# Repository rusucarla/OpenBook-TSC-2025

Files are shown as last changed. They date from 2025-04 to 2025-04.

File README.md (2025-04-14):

# Proiect TSC 2025 - OpenBook

## 1.O diagramă bloc cu toate componentele proiectului și cum sunt ele legate

```mermaid
graph TD
    
    USB["USB-C Connector(ESD Protection)"] -->|5V| CHG["Battery Charger (MCP73831)"]
    CHG -->|Charging| BATT["Li-Po Battery (2500mAh)"]
    BATT --> LDO["3.3V LDO Regulator (XC6220)"]

    LDO -->|3.3V| ESP["ESP32-C6-WROOM-1(MCU)"]

    ESP -- I2C --> RTC["Real Time Clock(DS3231)"]
    ESP -- I2C --> BME["Environmental Sensor(BME688)"]
    ESP -- I2C --> FUEL["Battery Fuel Gauge(MAX17048)"]
    ESP -- I2C --> QWIIC["Qwiic / Stemma QT"]

    ESP -- SPI --> FLASH["External NOR Flash(W25Q512)"]
    ESP -- SPI --> SD["MicroSD Card Slot"]
    ESP -- SPI --> EPD_HEADER["E-Paper Display Header"]

    EPD_HEADER --> EPD_DRIVER["EPD Driver Circuit"]
    EPD_DRIVER --> EPD_POW["EPD HV Power"]
    LDO --> EPD_HEADER

    ESP -- GPIO --> BUTTONS["3x Buttons:BOOT, CHANGE, RESET"]

    USB -- USB D+/D- --> ESP
```
## 2. BOM-ul (coloanele cu N/A sunt duplicate ale unui tip de componentă și am pus date doar la prima apariție a acelui tip de componentă)

Încă o observație, TP-ul si SJ-urile au fost modelate de către mine și astfel nu au model cu link sau data sheet.

| Name of component | Device | Check Prices | DataSheet |
|---|---|---|---|
| BOOT_BUTTON | BUTTON_CUSYOMV1 | https://industry.panasonic.com/global/en/products/control/switch/light-touch/number/evqpuj02k | https://industry.panasonic.com/global/en/products/control/switch/light-touch/number/evqpuj02k |
| C1 | ESP32_WROVER_EAGLE-LTSPICE_CC0402 | https://industry.panasonic.com/global/en/products/control/switch/light-touch/number/evqpuj02k | https://industry.panasonic.com/global/en/products/control/switch/light-touch/number/evqpuj02k |
| C1_BAT | ESP32_WROVER_EAGLE-LTSPICE_CC0402 | #N/A | #N/A |
| C1_BAT1 | EAGLE-LTSPICE_CC0402 | #N/A | #N/A |
| C1_BAT2 | EAGLE-LTSPICE_CC0402 | #N/A | #N/A |
| C2 | ESP32_WROVER_EAGLE-LTSPICE_CC0402 | #N/A | #N/A |
| C2_BAT\ | ESP32_WROVER_EAGLE-LTSPICE_CC0402 | #N/A | #N/A |
| C3 | RCL_CPOL-EUCT3528 | #N/A | #N/A |
| C4 | ESP32_WROVER_EAGLE-LTSPICE_CC0402 | #N/A | #N/A |
| C4_USB | ESP32_WROVER_EAGLE-LTSPICE_CC0402 | #N/A | #N/A |
| C5 | ESP32_WROVER_EAGLE-LTSPICE_CC0402 | #N/A | #N/A |
| C5_USB | ESP32_WROVER_EAGLE-LTSPICE_CC0402 | #N/A | #N/A |
| C6 | ESP32_WROVER_EAGLE-LTSPICE_CC0402 | #N/A | #N/A |
| C7 | ESP32_WROVER_EAGLE-LTSPICE_CC0402 | #N/A | #N/A |
| C8 | ESP32_WROVER_EAGLE-LTSPICE_CC0402 | #N/A | #N/A |
| C9 | EAGLE-LTSPICE_CC0402 | #N/A | #N/A |
| C10 | ESP32_WROVER_EAGLE-LTSPICE_CC0402 | #N/A | #N/A |
| C10_SUPERCAP | CPH3225A | https://www.snapeda.com/parts/CPH3225A/Seiko+Instruments/view-part/?ref=eda | https://www.snapeda.com/parts/CPH3225A/Seiko+Instruments/view-part/?ref=eda |
| CHANGE_BUTTON | BUTTON_CUSYOMV1 | https://industry.panasonic.com/global/en/products/control/switch-light-touch/number/evqpuj02k | https://industry.panasonic.com/global/en/products/control/switch-light-touch/number/evqpuj02k |
| CHG_LED | ADAFRUIT_LEDCHIP-LED0603 | https://www.snapeda.com/parts/KP-1608SURCK/Kingbright/view-part/?ref=search&t=LED%200603 | https://www.snapeda.com/parts/KP-1608SURCK/Kingbright/view-part/?ref=search&t=LED%200603 |
| C_DELAY | ESP32_WROVER_EAGLE-LTSPICE_CC0402 | #N/A | #N/A |
| D1 | USBLC6-2SC6Y | https://www.snapeda.com/parts/USBLC6-2SC6Y/STMicroelectronics/view-part/?ref=eda | https://www.snapeda.com/parts/USBLC6-2SC6Y/STMicroelectronics/view-part/?ref=eda |
| D2 | ESP32_WROVER_AVX---SD0805S020S1R0_AVX_... | https://eu.mouser.com/ProductDetail/KYOCERA-AVX/SD0805S020S1R0?qs=jCA%252BPfw4LHbpkAoSnwrdjw%3D%3D | http://datasheets.avx.com/schottky.pdf |
| D3 | MBR0530 | https://eu.mouser.com/ProductDetail/KYOCERA-AVX/SD0805S020S1R0?qs=jCA%252BPfw4LHbpkAoSnwrdjw%3D%3D | https://eu.mouser.com/ProductDetail/KYOCERA-AVX/SD0805S020S1R0?qs=jCA%252BPfw4LHbpkAoSnwrdjw%3D%3D |
| D4 | MBR0530 | https://www.snapeda.com/parts/MBR0530/Onsemi/view-part/?ref=eda | https://www.snapeda.com/parts/MBR0530/Onsemi/view-part/?ref=eda |
| D5 | MBR0530 | https://www.snapeda.com/parts/MBR0530/Onsemi/view-part/?ref=eda | https://www.snapeda.com/parts/MBR0530/Onsemi/view-part/?ref=eda |
| D6 | PGB1010603MR | https://www.snapeda.com/parts/PGB1010603MR/Littelfuse/view-part/?ref=eda | https://www.snapeda.com/parts/PGB1010603MR/Littelfuse/view-part/?ref=eda |
| D7 | ESP32_WROVER_AVX---SD0805S020S1R0_AVX_... | https://eu.mouser.com/ProductDetail/KYOCERA-AVX/SD0805S020S1R0?qs=jCA%252BPfw4LHbpkAoSnwrdjw%3D%3D | http://datasheets.avx.com/schottky.pdf |
| D8 | PGB1010603MR | https://www.snapeda.com/parts/PGB1010603MR/Littelfuse/view-part/?ref=eda | https://www.snapeda.com/parts/PGB1010603MR/Littelfuse/view-part/?ref=eda |
| D9 | PGB1010603MR | https://www.snapeda.com/parts/PGB1010603MR/Littelfuse/view-part/?ref=eda | https://www.snapeda.com/parts/PGB1010603MR/Littelfuse/view-part/?ref=eda |
| D10 | PGB1010603MR | https://www.snapeda.com/parts/PGB1010603MR/Littelfuse/view-part/?ref=eda | https://www.snapeda.com/parts/PGB1010603MR/Littelfuse/view-part/?ref=eda |
| D11 | PGB1010603MR | https://www.snapeda.com/parts/PGB1010603MR/Littelfuse/view-part/?ref=eda | https://www.snapeda.com/parts/PGB1010603MR/Littelfuse/view-part/?ref=eda |
| D12 | PGB1010603MR | https://www.snapeda.com/parts/PGB1010603MR/Littelfuse/view-part/?ref=eda | https://www.snapeda.com/parts/PGB1010603MR/Littelfuse/view-part/?ref=eda |
| EPD_C1 | ESP32_WROVER_EAGLE-LTSPICE_CC0402 | #N/A | #N/A |
| EPD_C2 | ESP32_WROVER_EAGLE-LTSPICE_CC0402 | #N/A | #N/A |
| EPD_C5 | ESP32_WROVER_EAGLE-LTSPICE_CC0402 | #N/A | #N/A |
| EPD_C6 | ESP32_WROVER_EAGLE-LTSPICE_CC0402 | #N/A | #N/A |
| EPD_C7 | ESP32_WROVER_EAGLE-LTSPICE_CC0402 | #N/A | #N/A |
| EPD_C8 | ESP32_WROVER_EAGLE-LTSPICE_CC0402 | #N/A | #N/A |
| EPD_C9 | ESP32_WROVER_EAGLE-LTSPICE_CC0402 | #N/A | #N/A |
| EPD_C10 | ESP32_WROVER_EAGLE-LTSPICE_CC0402 | #N/A | #N/A |
| EPD_C11 | ESP32_WROVER_EAGLE-LTSPICE_CC0402 | #N/A | #N/A |
| EPD_C12 | ESP32_WROVER_EAGLE-LTSPICE_CC0402 | #N/A | #N/A |
| IC1 | BD5229G-TR | https://componentsearchengine.com/part-view/BD5229G-TR/ROHM%20Semiconductor | https://componentsearchengine.com/part-view/BD5229G-TR/ROHM%20Semiconductor |
| IC4 | XC6220A331MR-G | https://componentsearchengine.com/part-view/XC6220A331MR-G/Torex | https://componentsearchengine.com/part-view/XC6220A331MR-G/Torex |
| J1 | FH34SRJ-24S-0.5SH_99_ | https://componentsearchengine.com/part-view/XC6220A331MR-G/Torex | https://componentsearchengine.com/part-view/XC6220A331MR-G/Torex |
| J2 | SAMACSYS_PARTS_USB4110-GF-A | https://componentsearchengine.com/part-view/USB4110-GF-A/GCT%20(GLOBAL%20CONNECTOR%20TECHNOLOGY | https://componentsearchengine.com/part-view/USB4110-GF-A/GCT%20(GLOBAL%20CONNECTOR%20TECHNOLOGY |
| J3 | QWIIC_CONNECTORJS-1MM | #N/A | #N/A |
| J4 | 112A-TAAR-R03_ATTEND | https://store.comet.srl.ro/Catalogue/Product/43497/ | https://store.comet.srl.ro/Catalogue/Product/43497/ |
| L1 | 744043680IND_4828-WE-TPC_WRE | https://eu.mouser.com/ProductDetail/Wurth-Elektronik/744043680?qs=PGXP4M47uW6VkZq%252BkzjrHA%3D%3D | https://eu.mouser.com/ProductDetail/Wurth-Elektronik/744043680?qs=PGXP4M47uW6VkZq%252BkzjrHA%3D%3D |
| PFMF.050.1 | ESP32C6_VARISTORCN1812 | https://www.mouser.co.uk/ProductDetail/EPCOS-TDK/B72520T0350K062?qs=dEfas%2FXlABIszF52uu7vrg%3D%3D | https://www.mouser.co.uk/ProductDetail/EPCOS-TDK/B72520T0350K062?qs=dEfas%2FXlABIszF52uu7vrg%3D%3D |
| Q1 | ESP32_WROVER_SPARKFUN-DISCRETESEMI_MOSFET_...| https://componentsearchengine.com/part-view/DMG2305UX-7/Diodes%20Incorporated | https://componentsearchengine.com/part-view/DMG2305UX-7/Diodes%20Incorporated |
| Q2 | ESP32_WROVER_SPARKFUN-DISCRETESEMI_MOSFET_...| #N/A | #N/A |
| Q3 | D8 | https://componentsearchengine.com/part-view/SI1308EDL-T1-GE3/Vishay | https://componentsearchengine.com/part-view/SI1308EDL-T1-GE3/Vishay |
| R1 | ESP32_WROVER_EAGLE-LTSPICE_RR0402 | #N/A | #N/A |
| R1-PINH | ESP32_WROVER_EAGLE-LTSPICE_RR0402 | #N/A | #N/A |
| R1-PINH1 | ESP32_WROVER_EAGLE-LTSPICE_RR0402 | #N/A | #N/A |
| R1_BAT | ESP32_WROVER_EAGLE-LTSPICE_RR0402 | #N/A | #N/A |
| R1_PWRUSB | ESP32_WROVER_EAGLE-LTSPICE_RR0402 | #N/A | #N/A |
| R2 | ESP32_WROVER_EAGLE-LTSPICE_RR0402 | https://componentsearchengine.com/part-view/R0402%201%25%20100%20K%20(RC0402FR-07100KL | https://componentsearchengine.com/part-view/R0402%201%25%20100%20K%20(RC0402FR-07100KL |
| R2-PINH | ESP32_WROVER_EAGLE-LTSPICE_RR0402 | #N/A | #N/A |
| R2-PINH1 | ESP32_WROVER_EAGLE-LTSPICE_RR0402 | #N/A | #N/A |
| R2-USB | ESP32_WROVER_EAGLE-LTSPICE_RR0402 | #N/A | #N/A |
| R2-USB1 | ESP32_WROVER_EAGLE-LTSPICE_RR0402 | #N/A | #N/A |
| R2_BAT | ESP32_WROVER_EAGLE-LTSPICE_RR0402 | #N/A | #N/A |
| R3 | ESP32_WROVER_EAGLE-LTSPICE_RR0402 | #N/A | #N/A |
| R4 | ESP32_WROVER_EAGLE-LTSPICE_RR0402 | #N/A | #N/A |
| R5 | ESP32_WROVER_EAGLE-LTSPICE_RR0402 | #N/A | #N/A |
| R6 | ESP32_WROVER_EAGLE-LTSPICE_RR0402 | #N/A | #N/A |
| R7 | ESP32_WROVER_EAGLE-LTSPICE_RR0402 | #N/A | #N/A |
| R8 | ESP32_WROVER_EAGLE-LTSPICE_RR0402 | #N/A | #N/A |
| R9 | ESP32_WROVER_EAGLE-LTSPICE_RR0402 | #N/A | #N/A |
| R10 | ESP32_WROVER_EAGLE-LTSPICE_RR0402 | #N/A | #N/A |
| RESET_BUTTON | BUTTON_CUSYOMV1 | https://industry.panasonic.com/global/en/products/control/switch/light-touch/number/evqpuj02k | https://industry.panasonic.com/global/en/products/control/switch/light-touch/number/evqpuj02k |
| R_BOOT | ESP32_WROVER_EAGLE-LTSPICE_RR0402 | #N/A | #N/A |
| R_CAPACITOR | ESP32_WROVER_EAGLE-LTSPICE_RR0402 | #N/A | #N/A |
| R_CHANGE | ESP32_WROVER_EAGLE-LTSPICE_RR0402 | #N/A | #N/A |
| R_CL1 | ESP32_WROVER_EAGLE-LTSPICE_RR0402 | #N/A | #N/A |
| R_RESET | ESP32_WROVER_EAGLE-LTSPICE_RR0402 | #N/A | #N/A |
| SENSOR2 | ESP32_WROVER_BME680_BME680 | https://www.snapeda.com/parts/BME680/Bosch/view-part/?welcome=home | https://www.snapeda.com/parts/BME680/Bosch/view-part/?welcome=home |
| SJ1 | SJ | https://grabcad.com/library/solder-jumpers-1 | https://grabcad.com/library/solder-jumpers-1 |
| TP1 | TPTP20R | #N/A | #N/A |
| TP2 | TPTP20R | #N/A | #N/A |
| TP3 | TPTP20R | #N/A | #N/A |
| TP4 | TPTP20R | #N/A | #N/A |
| TP5 | TPTP20R | #N/A | #N/A |
| TP6 | TPTP20R | #N/A | #N/A |
| TP7 | TPTP20R | #N/A | #N/A |
| TP8 | TPTP20R | #N/A | #N/A |
| TP9 | TPTP20R | #N/A | #N/A |
| TP10 | TPTP20R | #N/A | #N/A |
| TP11 | TPTP20R | #N/A | #N/A |
| TP12 | TPTP20R | #N/A | #N/A |
| TP13 | TPTP20R | #N/A | #N/A |
| TP14 | TPTP20R | #N/A | #N/A |
| TP15 | TPTP20R | #N/A | #N/A |
| TP16 | TPTP20R | #N/A | #N/A |
| TP17 | TPTP20R | #N/A | #N/A |
| U1 | W25Q512JVEIQ | https://www.snapeda.com/parts/W25Q512JVEIQ/Winbond+Electronics/view-part/?ref=eda | https://www.snapeda.com/parts/W25Q512JVEIQ/Winbond+Electronics/view-part/?ref=eda |
| U2 | ESP32-C6-WROOM-1-N8 | https://www.snapeda.com/parts/ESP32-C6-WROOM-1-N8/Espressif+Systems/view-part/?ref=eda | https://www.snapeda.com/parts/ESP32-C6-WROOM-1-N8/Espressif+Systems/view-part/?ref=eda |
| U3 | DS3231SN# | https://www.snapeda.com/parts/DS3231SN%23/Analog+Devices/view-part/?ref=eda | https://www.snapeda.com/parts/DS3231SN%23/Analog+Devices/view-part/?ref=eda |
| U4 | MAX17048G+T10 | https://www.snapeda.com/parts/MAX17048G+T10/Analog+Devices/view-part/?ref=eda | https://www.snapeda.com/parts/MAX17048G+T10/Analog+Devices/view-part/?ref=eda |
| U5 | ESP32_WROVER_SPARKFUN-IC-POWER_MCP73831 | https://eu.mouser.com/ProductDetail/Microchip-Technology/MCP73831T-2ACI-OT?qs=yUQqVecv4qvbBQBGbHx0Mw%3D%3Dcf | https://eu.mouser.com/ProductDetail/Microchip-Technology/MCP73831T-2ACI-OT?qs=yUQqVecv4qvbBQBGbHx0Mw%3D%3Dcf |

## 3. Descrierea in detaliu a functionalitatilor hardware 

### 1. Microcontroller – ESP32-C6

- **Procesor**: 32-bit RISC-V, cu frecvență de până la 160MHz.
    
- **Memorie**: 512KB SRAM intern și 8MB flash extern (W25Q512JVEIQ).
    
- **Conectivitate**: Wi-Fi 6 (802.11ax), Bluetooth 5 (LE), USB 2.0 (full-speed).
    
- **Periferice**: SPI, I²C, UART, GPIO multiple.
    
- **Consum**: Posibilitate de moduri low-power (sleep, deep sleep).
---

### 2. Afișajul E-Paper (7.5 inch)

- **Model**: Waveshare (sau echivalent) cu rezoluție 800×480.
    
- **Interfață**: 4-wire SPI + semnale de control (CS, DC, RST, BUSY).
    
- **Consum**: Foarte redus în mod static (după refresh), dar necesită un curent mai mare în timpul refresh-ului (aprox. 15–25mA, în funcție de modul de actualizare).

**De ce l-am ales?**  
E-paper consumă energie doar când reîmprospătează imaginea. Este ideal pentru un e-reader, deoarece menține afișajul vizibil fără consum suplimentar.

---

### 3. Senzor de Mediu – BME688

- **Parametri măsurați**: Temperatură, Umiditate, Presiune și Calitate aer (VOC/eCO2).
    
- **Interfață**: I²C la 400kHz (SDA și SCL).
    
- **Consum**: Foarte mic (în jur de 2.1µA în standby și până la câteva mA în mod de măsurare).

**De ce BME688?**  
Integrează într-un singur cip mai multe tipuri de măsurători de mediu, util pentru a afișa date despre condițiile de citire (temperatură, umiditate etc.).

---

### 4. Baterie și Managementul Energiei

- **Baterie Li-Po 2500mAh** (3.7V nominal).
    
- **IC de Încărcare**: MCP73831 (Microchip) – încărcare Li-Po prin USB-C (până la 1A).
    
- **Fuel Gauge**: MAX17048 – monitorizează nivelul de încărcare, tensiunea și starea bateriei (I²C).
    
- **LDO**: XC6220A331MR-G (exemplu) sau echivalent, pentru a asigura 3.3V stabil pentru microcontroller și restul componentelor.

**De ce aceste componente?**

- MCP73831 este un controler simplu, fiabil și compatibil cu USB.
    
- MAX17048 oferă date precise despre nivelul bateriei și poate alerta asupra unei baterii descărcate.

---

### 5. Butoane (3x Tactile Switch)

- **Tip**: Tactile switch Panasonic (sau echivalent).
    
- **Funcții**: Navigare meniu, selectare opțiune, întoarcere pagină etc.
    
- **Conexiune**: Fiecare buton se leagă la un GPIO al ESP32-C6 printr-un circuit de debouncing (rezistență și condensator) sau se poate face debouncing în firmware.

---

### 6. USB-C Port

- **Rol**: Încărcare baterie + Transfer de date (USB 2.0 full-speed).
    
- **Protecții**: ESD (USBLC6-2SC6Y) + rezistențe de terminare.
    
- **Posibilitate**: Actualizări firmware prin USB (bootloader + tool extern) sau direct OTA prin Wi-Fi.

---

### 7. Conector Qwiic (I²C)

- Conector standard cu 4 pini: VCC, GND, SDA, SCL.
    
- Permite atașarea rapidă a altor senzori sau module I²C (expansiune, testare, prototipare rapidă).

---

### 8. SD Memory Card Connector (112A-TAAR-R03)

- **Rol**: Posibilitate de stocare externă pentru e-book-uri, log-uri sau update-uri firmware.
    
- **Interfață**: Poate fi SD (1-bit / 4-bit) sau SPI, în funcție de configurația firmware-ului.

---

### 9. RTC – DS3231

- **Funcție**: Asigură un ceas de timp real foarte precis.
    
- **Interfață**: I²C (aceeași magistrală cu BME688 și MAX17048).
    
- **Backup**: Supercondensator sau baterie secundară pentru a menține timpul și în absența alimentării principale.

---

### 10. Memorii Suplimentare

- **W25Q512JVEIQ** (Flash extern) – conectat la ESP32-C6 prin SPI dedicat (quad SPI).
    
    - Aici se stochează firmware-ul și datele mari (e-book-uri etc.).

---

### Comunicarea și Interfețele

1. **SPI**:
    
    - Ecranul e-paper (4-wire SPI).
        
    - Flash extern (quad SPI dedicat, pinii sunt în mare parte fixați de designul ESP32-C6).
        
2. **I²C**:
    
    - Senzorul BME688.
        
    - Fuel Gauge MAX17048.
        
    - RTC DS3231.
        
    - Qwiic Connector (pentru potențiale extensii).
        
3. **USB 2.0**:
    
    - Date + alimentare/încărcare prin USB-C.
        
4. **GPIO**:
    
    - Butoane (3x intrări digitale).
        
    - Eventual semnale de control suplimentare (reset display, busy pin display, semnal de enable alimentare etc.).

### Calcul Simplificat al Consumului

| Modul | Consum tipic |
| --- | --- |
| **ESP32-C6** (activ) | ~80mA (Wi-Fi activ) / < 10mA (idle) |
| **E-Paper** (refresh) | ~15–25mA (doar în timpul refresh-ului) |
| **BME688** (activ) | ~3.6mA (peak) / 2.1µA (sleep) |
| **MAX17048** (fuel gauge) | ~50µA |
| **DS3231** (RTC) | ~3.5mA (activ) / <1µA (back-up) |
| **MCP73831** (charger) | Consum diferit în funcție de curentul de încărcare:<br>- *500 mA* (standard)<br>- *1 A* (dacă design-ul suportă încărcare mai rapidă) |

#### Mod Activ + Wi-Fi

- În timpul activării Wi-Fi (pentru descărcarea e-book-urilor sau actualizarea conținutului) și al refresh-ului ecranului e-paper, **consumul total** al sistemului (ESP32-C6 + e-paper + senzori) poate ajunge la **100–150 mA**.  
- Această valoare **include** ESP32-C6 în mod Wi-Fi activ, senzori și curentul suplimentar de ~15–25 mA în timpul refresh-ului e-paper.

#### Deep Sleep / Standby

- **ESP32-C6** poate intra în deep sleep cu un consum de ordinul zecilor de microamperi (~70 µA dacă este bine optimizat și cu periferice oprite).  
- Ceilalți senzori și componente pot fi dezactivați sau puși în moduri de consum redus, contribuind cu încă câțiva µA (RTC, fuel gauge etc.).  
- Totalul în deep sleep poate fi menținut sub **100 µA** dacă sunt implementate corect modurile de consum redus pentru fiecare componentă.

#### Exemplu de Calcul pentru Autonomie

Cu o **baterie de 2500 mAh**, considerăm un ciclu de funcționare ipotetic:

- **95% din timp** dispozitivul este în deep sleep (~70 µA).  
- **5% din timp** este în mod activ (~120 mA), cu Wi-Fi pornit și e-paper folosit.  

1. **Consum în deep sleep (95% din timp)**  
     $I_{\mathrm{deep\_sleep}} = 70\,\mu A$
   
3. **Consum în mod activ (5% din timp)**  
   $I_{\mathrm{activ}} \approx 120\,mA$

4. **Media consumului orar**  
   $I_{\mathrm{mediu}} = 0.95 \times 70\,\mu A + 0.05 \times 120\,mA = (0.95 \times 0.07\,mA) + (0.05 \times 120\,mA) = 0.0665\,mA + 6\,mA = \approx 6.07\,mA$

5. **Autonomie teoretică**  
   $\text{Autonomie} = \frac{Capacitatea\ Bateriei}{I_{\mathrm{mediu}}}
     \approx \frac{2500\,mAh}{6.07\,mA} \approx 412\,ore \approx 17\,zile$

Dacă mai optimizăm timpul activ (de exemplu, îl reducem la 2–3% din timp) sau scădem consumul de vârf, se poate ajunge la **3–4 săptămâni**. Totuși, în practică, autonomia depinde foarte mult de:

- **Frecvența refresh-ului** e-paper  
- **Durata și frecvența conexiunilor Wi-Fi**  
- **Alți consumatori** (de ex. LED-uri de stare sau module suplimentare)

## 4. Descrieți în detaliu ce pini ai ESP32-C6 sunt folosiți pentru fiecare componentă și de ce

| Pin ESP32-C6 | Componentă / Semnal | De ce? |
| --- | --- | --- |
| **GPIO1 (SDA)** | I²C SDA (BME688, MAX17048, DS3231, Qwiic) | Partajare magistrală I²C pentru toți senzorii și RTC. |
| **GPIO2 (SCL)** | I²C SCL (BME688, MAX17048, DS3231, Qwiic) | Linia de clock pentru I²C. |
| **GPIO5** | SPI MISO (E-Paper) | Citirea datelor/statusului display-ului (dacă e suportat). |
| **GPIO6** | SPI MOSI (E-Paper) | Trimiterea datelor către e-paper. |
| **GPIO7** | SPI CLK (E-Paper) | Semnal de clock pentru e-paper. |
| **GPIO8** | SPI CS (E-Paper) | Chip Select pentru e-paper. |
| **GPIO9** | E-Paper DC (Data/Command) | Semnal care diferențiază datele de comenzile pentru afișaj. |
| **GPIO10** | E-Paper RST | Reset hardware pentru e-paper. |
| **GPIO11** | E-Paper BUSY | Intrare din display, indică dacă este ocupat. |
| **GPIO12** | Button #1 | Intrare digitală pentru buton (ex. NEXT page). |
| **GPIO13** | Button #2 | Intrare digitală pentru buton (ex. PREV page). |
| **GPIO14** | Button #3 | Intrare digitală pentru buton (ex. MENU/OK). |
| **GPIO15** | MAX17048 ALERT (opțional) | Avertizare nivel baterie scăzut. |
| **GPIO16** | USB D+ (intern la USB PHY) | Pin dedicat pentru USB 2.0. (În mod normal pin hardware fix). |
| **GPIO17** | USB D- (intern la USB PHY) | Pin dedicat pentru USB 2.0. (La fel, pin fix). |
| **GPIO18** | LED de status (opțional) | Indicator pentru diverse stări (Wi-Fi, încărcare, etc.). |
| **GPIO19** | SD Card CS (opțional) | Chip Select pentru cardul SD (dacă se folosește SPI). |
| **GPIO20** | SD Card MISO (opțional) | Intrare date de la card SD. |
| **GPIO21** | SD Card MOSI (opțional) | Ieșire date către card SD. |
| **GPIO4** | SD Card CLK (opțional) | Semnal de clock pentru card SD (SPI). |

## Orice altceva 

Design log-ul poate fi gasit pe [autodesk](https://a360.co/4kX1RTV)

Exista o incompatibilitate intre .fbrd si .brd cand vine vorba de via stching. Am pus si fisierul .fbrd pentru a se oberva diferenta.

Am decis sa redenumesc TP-urile pentru a fi mai usor de gestionat.

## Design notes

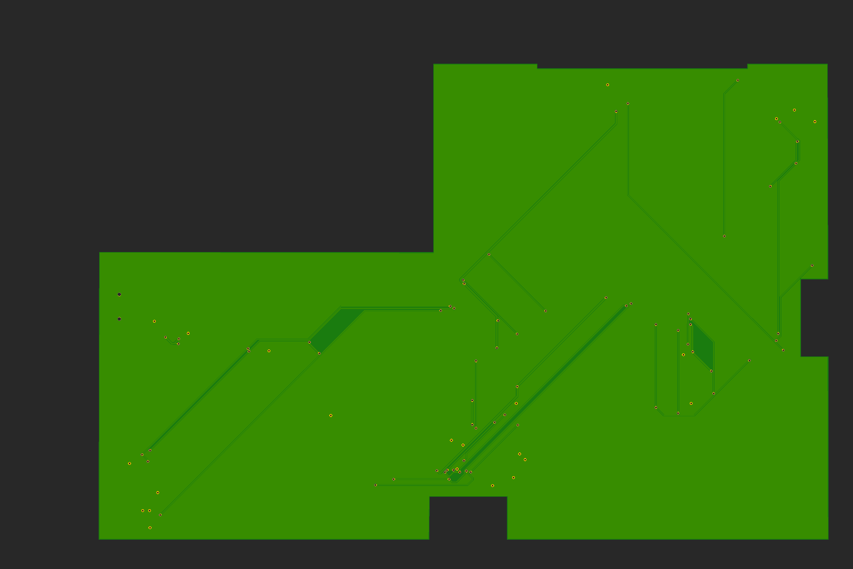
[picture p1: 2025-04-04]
Images/OpenBook_Board_View_Bottom.png

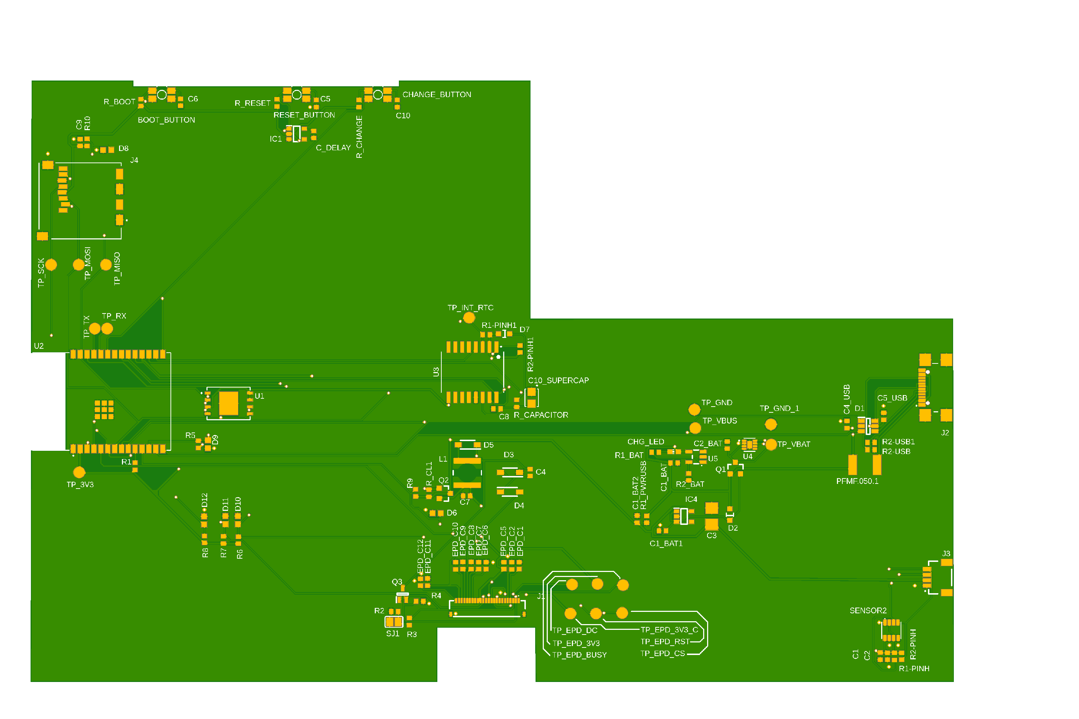
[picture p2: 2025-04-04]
Images/OpenBook_Board_View_Top.png

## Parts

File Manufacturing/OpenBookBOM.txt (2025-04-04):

Partlist exported from Fusion Hub: Fusion-Carla   Project: Admin Project  Board: OpenBook v71 at 04.04.2025 15:21

Part          Value                                                                          Device                                                                         Package                                                Description                                                                                                                                                                                                                                                                                                                                                                                                                                                                                          PARTNAME   
BOOT_BUTTON   BUTTON_CUSYOMV1                                                                BUTTON_CUSYOMV1                                                                MYBUTTON                                                                                                                                                                                                                                                                                                                                                                                                                                                                                                                                                               
C1            100nF                                                                          ESP32_WROVER_EAGLE-LTSPICE_CC0402                                              ESP32_WROVER_EAGLE-LTSPICE_C0402                       CAPACITOR, European symbol                                                                                                                                                                                                                                                                                                                                                                                                                                                                                      
C1_BAT        4.7uF                                                                          ESP32_WROVER_EAGLE-LTSPICE_CC0402                                              ESP32_WROVER_EAGLE-LTSPICE_C0402                       CAPACITOR, European symbol                                                                                                                                                                                                                                                                                                                                                                                                                                                                                      
C1_BAT1       4.7uF                                                                          ESP32_WROVER_EAGLE-LTSPICE_CC0402                                              ESP32_WROVER_EAGLE-LTSPICE_C0402                       CAPACITOR, European symbol                                                                                                                                                                                                                                                                                                                                                                                                                                                                                      
C1_BAT2       4.7uF                                                                          ESP32_WROVER_EAGLE-LTSPICE_CC0402                                              ESP32_WROVER_EAGLE-LTSPICE_C0402                       CAPACITOR, European symbol                                                                                                                                                                                                                                                                                                                                                                                                                                                                                      
C2            100nF                                                                          ESP32_WROVER_EAGLE-LTSPICE_CC0402                                              ESP32_WROVER_EAGLE-LTSPICE_C0402                       CAPACITOR, European symbol                                                                                                                                                                                                                                                                                                                                                                                                                                                                                      
C2_BAT\       4.7uF                                                                          ESP32_WROVER_EAGLE-LTSPICE_CC0402                                              ESP32_WROVER_EAGLE-LTSPICE_C0402                       CAPACITOR, European symbol                                                                                                                                                                                                                                                                                                                                                                                                                                                                                      
C3            100uF TANT                                                                     RCL_CPOL-EUCT3528                                                              RCL_CT3528                                             POLARIZED CAPACITOR, European symbol                                                                                                                                                                                                                                                                                                                                                                                                                                                                            
C4            4.7uF/25V                                                                      ESP32_WROVER_EAGLE-LTSPICE_CC0402                                              ESP32_WROVER_EAGLE-LTSPICE_C0402                       CAPACITOR, European symbol                                                                                                                                                                                                                                                                                                                                                                                                                                                                                      
C4_USB        100nF                                                                          ESP32_WROVER_EAGLE-LTSPICE_CC0402                                              ESP32_WROVER_EAGLE-LTSPICE_C0402                       CAPACITOR, European symbol                                                                                                                                                                                                                                                                                                                                                                                                                                                                                      
C5            1uF                                                                            ESP32_WROVER_EAGLE-LTSPICE_CC0402                                              ESP32_WROVER_EAGLE-LTSPICE_C0402                       CAPACITOR, European symbol                                                                                                                                                                                                                                                                                                                                                                                                                                                                                      
C5_USB        4.7µF                                                                          ESP32_WROVER_EAGLE-LTSPICE_CC0402                                              ESP32_WROVER_EAGLE-LTSPICE_C0402                       CAPACITOR, European symbol                                                                                                                                                                                                                                                                                                                                                                                                                                                                                      
C6            100nF                                                                          ESP32_WROVER_EAGLE-LTSPICE_CC0402                                              ESP32_WROVER_EAGLE-LTSPICE_C0402                       CAPACITOR, European symbol                                                                                                                                                                                                                                                                                                                                                                                                                                                                                      
C7            10uF                                                                           ESP32_WROVER_EAGLE-LTSPICE_CC0402                                              ESP32_WROVER_EAGLE-LTSPICE_C0402                       CAPACITOR, European symbol                                                                                                                                                                                                                                                                                                                                                                                                                                                                                      
C8            100nF                                                                          ESP32_WROVER_EAGLE-LTSPICE_CC0402                                              ESP32_WROVER_EAGLE-LTSPICE_C0402                       CAPACITOR, European symbol                                                                                                                                                                                                                                                                                                                                                                                                                                                                                      
C9            100nF                                                                          EAGLE-LTSPICE_CC0402                                                           ESP32_WROVER_EAGLE-LTSPICE_C0402                       CAPACITOR, European symbol                                                                                                                                                                                                                                                                                                                                                                                                                                                                                      
C10           100nF                                                                          ESP32_WROVER_EAGLE-LTSPICE_CC0402                                              ESP32_WROVER_EAGLE-LTSPICE_C0402                       CAPACITOR, European symbol                                                                                                                                                                                                                                                                                                                                                                                                                                                                                      
C10_SUPERCAP  CPH3225A""                                                                     CPH3225A""                                                                     CAPCP3225X100N                                         Cap 0.011F 3.3V 1210 Flat Check availability                                                                                                                                                                                                                                                                                                                                                                                                                                                                    
CHANGE_BUTTON BUTTON_CUSYOMV1                                                                BUTTON_CUSYOMV1                                                                MYBUTTON                                                                                                                                                                                                                                                                                                                                                                                                                                                                                                                                                               
CHG_LED                                                                                      ADAFRUIT_LEDCHIP-LED0603                                                       ADAFRUIT_CHIP-LED0603                                  LED                                                                                                                                                                                                                                                                                                                                                                                                                                                                                                             
C_DELAY       100nF                                                                          ESP32_WROVER_EAGLE-LTSPICE_CC0402                                              ESP32_WROVER_EAGLE-LTSPICE_C0402                       CAPACITOR, European symbol                                                                                                                                                                                                                                                                                                                                                                                                                                                                                      
D1            USBLC6-2SC6Y                                                                   USBLC6-2SC6Y                                                                   SOT95P280X145-6N                                       Low Cap. ESD Protection Auto SOT-23-6 STMicroelectronics USBLC6-2SC6Y, Dual Uni-Directional TVS Diode Array, 6-Pin SOT-23                                                                                                                                                                                                                                                                                                                                                                                       
D2            ESP32_WROVER_AVX---SD0805S020S1R0_AVX_SD0805S020S1R0_0_0AVX_SD0805S020S1R0_0_0 ESP32_WROVER_AVX---SD0805S020S1R0_AVX_SD0805S020S1R0_0_0AVX_SD0805S020S1R0_0_0 ESP32_WROVER_AVX---SD0805S020S1R0_AVX_SD0805S020S1R0_0 Schottky Barrier Rectifier Diode                                                                                                                                                                                                                                                                                                                                                                                                                                                                                
D3            MBR0530                                                                        MBR0530                                                                        SOD3716X135N                                           ON SEMICONDUCTOR - MBR0530 - DIODE, SCHOTTKY, 0.5A, 30V, SOD-123                                                                                                                                                                                                                                                                                                                                                                                                                                                
D4            MBR0530                                                                        MBR0530                                                                        SOD3716X135N                                           ON SEMICONDUCTOR - MBR0530 - DIODE, SCHOTTKY, 0.5A, 30V, SOD-123                                                                                                                                                                                                                                                                                                                                                                                                                                                
D5            MBR0530                                                                        MBR0530                                                                        SOD3716X135N                                           ON SEMICONDUCTOR - MBR0530 - DIODE, SCHOTTKY, 0.5A, 30V, SOD-123                                                                                                                                                                                                                                                                                                                                                                                                                                                
D6            PGB1010603MR                                                                   PGB1010603MR                                                                   DIOC1608X36N                                           Check availability                                                                                                                                                                                                                                                                                                                                                                                                                                                                                              
D7            ESP32_WROVER_AVX---SD0805S020S1R0_AVX_SD0805S020S1R0_0_0AVX_SD0805S020S1R0_0_0 ESP32_WROVER_AVX---SD0805S020S1R0_AVX_SD0805S020S1R0_0_0AVX_SD0805S020S1R0_0_0 ESP32_WROVER_AVX---SD0805S020S1R0_AVX_SD0805S020S1R0_0 Schottky Barrier Rectifier Diode                                                                                                                                                                                                                                                                                                                                                                                                                                                                                
D8            PGB1010603MR                                                                   PGB1010603MR                                                                   DIOC1608X36N                                           Check availability                                                                                                                                                                                                                                                                                                                                                                                                                                                                                              
D9            PGB1010603MR                                                                   PGB1010603MR                                                                   DIOC1608X36N                                           Check availability                                                                                                                                                                                                                                                                                                                                                                                                                                                                                              
D10           PGB1010603MR                                                                   PGB1010603MR                                                                   DIOC1608X36N                                           Check availability                                                                                                                                                                                                                                                                                                                                                                                                                                                                                              
D11           PGB1010603MR                                                                   PGB1010603MR                                                                   DIOC1608X36N                                           Check availability                                                                                                                                                                                                                                                                                                                                                                                                                                                                                              
D12           PGB1010603MR                                                                   PGB1010603MR                                                                   DIOC1608X36N                                           Check availability                                                                                                                                                                                                                                                                                                                                                                                                                                                                                              
EPD_C1        1uF/50V                                                                        ESP32_WROVER_EAGLE-LTSPICE_CC0402                                              ESP32_WROVER_EAGLE-LTSPICE_C0402                       CAPACITOR, European symbol                                                                                                                                                                                                                                                                                                                                                                                                                                                                                      
EPD_C2        1uF/50V                                                                        ESP32_WROVER_EAGLE-LTSPICE_CC0402                                              ESP32_WROVER_EAGLE-LTSPICE_C0402                       CAPACITOR, European symbol                                                                                                                                                                                                                                                                                                                                                                                                                                                                                      
EPD_C5        1uF/50V                                                                        ESP32_WROVER_EAGLE-LTSPICE_CC0402                                              ESP32_WROVER_EAGLE-LTSPICE_C0402                       CAPACITOR, European symbol                                                                                                                                                                                                                                                                                                                                                                                                                                                                                      
EPD_C6        1uF/50V                                                                        ESP32_WROVER_EAGLE-LTSPICE_CC0402                                              ESP32_WROVER_EAGLE-LTSPICE_C0402                       CAPACITOR, European symbol                                                                                                                                                                                                                                                                                                                                                                                                                                                                                      
EPD_C7        1uF/50V                                                                        ESP32_WROVER_EAGLE-LTSPICE_CC0402                                              ESP32_WROVER_EAGLE-LTSPICE_C0402                       CAPACITOR, European symbol                                                                                                                                                                                                                                                                                                                                                                                                                                                                                      
EPD_C8        1uF/50V                                                                        ESP32_WROVER_EAGLE-LTSPICE_CC0402                                              ESP32_WROVER_EAGLE-LTSPICE_C0402                       CAPACITOR, European symbol                                                                                                                                                                                                                                                                                                                                                                                                                                                                                      
EPD_C9        1uF/50V                                                                        ESP32_WROVER_EAGLE-LTSPICE_CC0402                                              ESP32_WROVER_EAGLE-LTSPICE_C0402                       CAPACITOR, European symbol
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

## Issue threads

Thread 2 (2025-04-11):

sugestii README

alexandru-carutasu, 2025-04-11:
1. diagrama bloc recomand mai aerisita , sa se vada mai clar asocierile
2.a) la sectiunea de calcul simplificat al consumului : la  ESP32-C6 idea de range ul pt idle nu este descris , la MCP73831 se in loc de "Depinde de curentul de încărcare" recomand luarea a 2-3 cazuri pentru precizie
   b)„100–150mA” este o valoare plauzibilă pentru un ESP32 cu Wi-Fi activ, dar este posibil să nu includă consumul altor componente (de exemplu : senzori).
solutie: Mentioneaza dacă această valoare include și alte componente. De exemplu:
În modul Activ + Wi-Fi (de exemplu, descărcarea de cărți electronice, refresh al ecranului), consumul total de energie poate ajunge la 100–150mA, incluzând ESP32-C6 si refresh
c)afirmatia „se poate atinge o autonomie de cateva saptamani” este vaga si nu include un calcul detaliat.Cu o baterie de 2500mAh si presupunând că 95% din timp dispozitivul se afla în modul de repaus profund (~70µA) si 5% în modul activ (~120mA), autonomia estimata este de aproximativ 3–4 saptamani. Autonomia reala depinde de frecventa de refresh a ecranului si de utilizarea conexiunii Wi-Fi.

rusucarla, 2025-04-12:
1. Diagrama mai aerisita
2. Pentru fiecare punct:
a.  Pus 2 cazuri de incarcare
b. Mentionata influenta factorilor dati de componente
c. Scris o concluzie mai clara pentru autonomia device-ului

Closed 2025-04-12.

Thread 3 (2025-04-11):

Observatii minore

alexandru-carutasu, 2025-04-11:
->am observat niste iregularitati (nimic special) la specificatiile privind puterea si tensiunea
->din ce am vzt , la rutare unele trasee sunt cam apropiate , nu cred ca e ceva foarte important dar din ce am citit pot aparea interferente

rusucarla, 2025-04-12:
La rutare, am respectat prevederile din DRC si astfel nu cred ca ar trebui sa existe probleme. Iti mutlumesc pentru atentia la detaliu !

Closed 2025-04-12.

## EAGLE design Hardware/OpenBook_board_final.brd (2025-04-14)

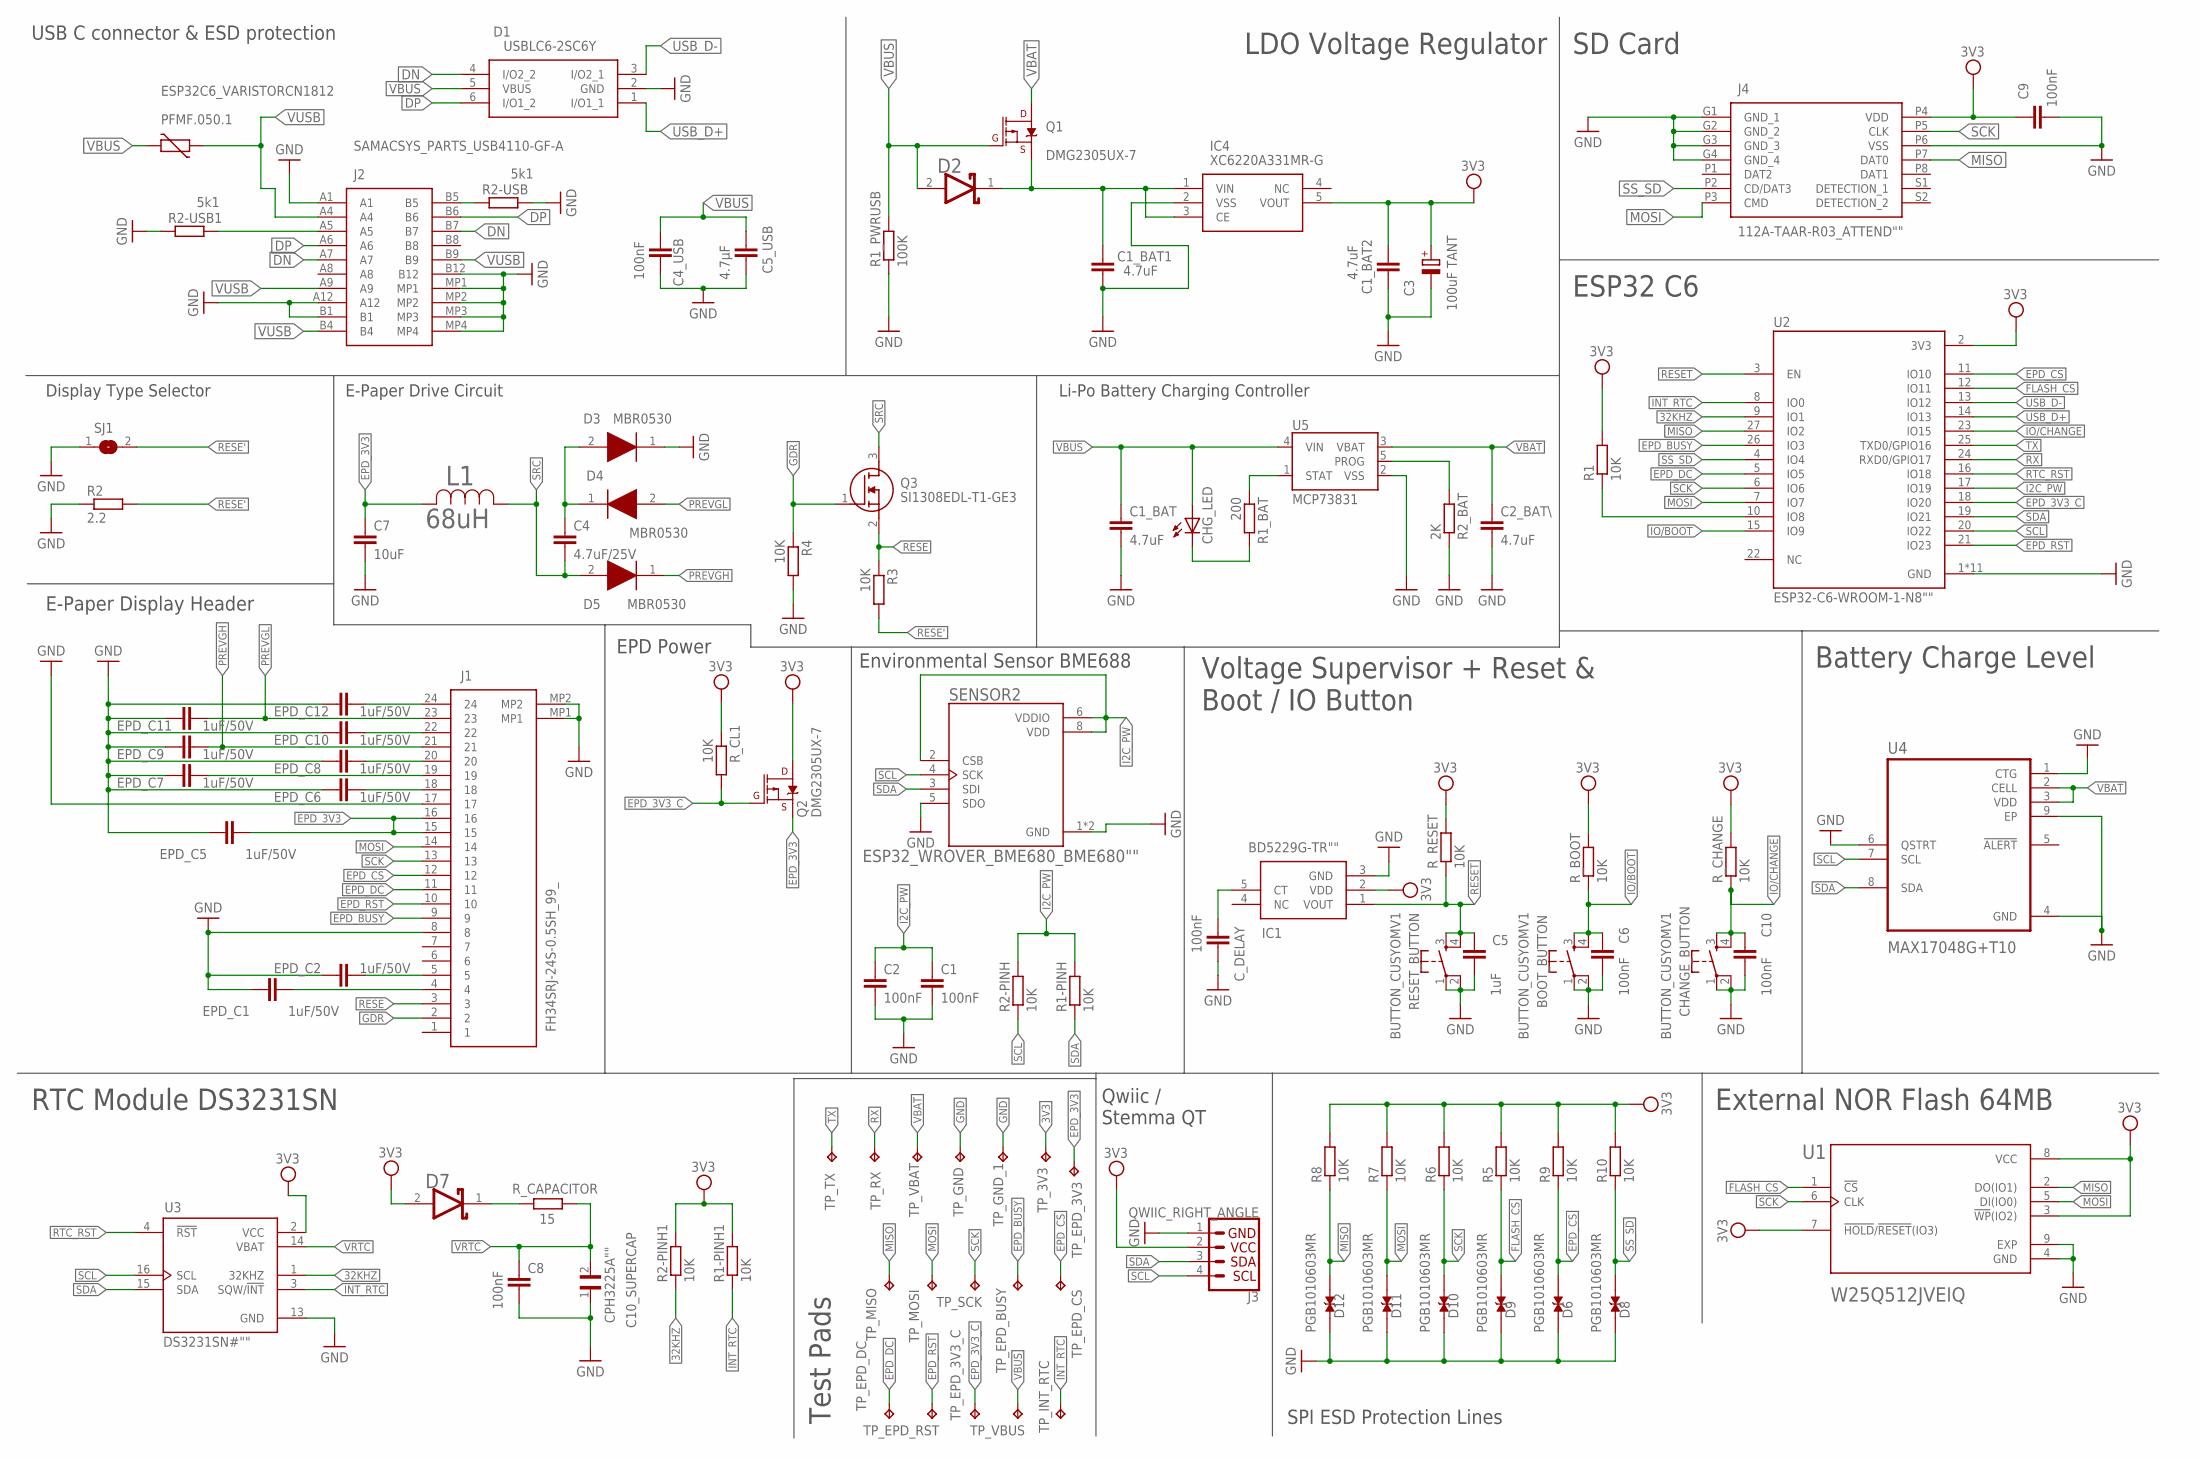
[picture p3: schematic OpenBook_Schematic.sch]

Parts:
BOOT_BUTTON: BUTTON_CUSYOMV1; MYBUTTON
C1, C2, C4_USB, C6, C8, C9, C10: 100nF; ESP32_WROVER_EAGLE-LTSPICE_C0402
C1_BAT, C1_BAT1, C1_BAT2, C2_BAT\: 4.7uF; ESP32_WROVER_EAGLE-LTSPICE_C0402
C3: 100uF TANT; RCL_CT3528
C4: 4.7uF/25V; ESP32_WROVER_EAGLE-LTSPICE_C0402
C5: 1uF; ESP32_WROVER_EAGLE-LTSPICE_C0402
C5_USB: 4.7μF; ESP32_WROVER_EAGLE-LTSPICE_C0402
C7: 10uF; ESP32_WROVER_EAGLE-LTSPICE_C0402
C10_SUPERCAP: CPH3225A""; CAPCP3225X100N
CHANGE_BUTTON: BUTTON_CUSYOMV1; MYBUTTON
CHG_LED: ADAFRUIT_LEDCHIP-LED0603; ADAFRUIT_CHIP-LED0603
C_DELAY: 100nF; ESP32_WROVER_EAGLE-LTSPICE_C0402
D1: USBLC6-2SC6Y; SOT95P280X145-6N
D2, D7: ESP32_WROVER_AVX---SD0805S020S1R0_AVX_SD0805S020S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; ESP32_WROVER_AVX---SD0805S020S1R0_AVX_SD0805S020S1R0_0
D3, D4, D5: MBR0530; SOD3716X135N
D6, D8, D9, D10, D11, D12: PGB1010603MR; DIOC1608X36N
EPD_C1, EPD_C2, EPD_C5, EPD_C6, EPD_C7, EPD_C8, EPD_C9, EPD_C10, EPD_C11, EPD_C12: 1uF/50V; ESP32_WROVER_EAGLE-LTSPICE_C0402
IC1: BD5229G-TR""; SOT95P280X125-5N
IC4: XC6220A331MR-G; SOT95P280X120-5N
J1: FH34SRJ-24S-0.5SH_99_; FH34SRJ24S05SH99
J2: SAMACSYS_PARTS_USB4110-GF-A; SAMACSYS_PARTS_USB4110GFA
J3: QWIIC_RIGHT_ANGLE; JST04_1MM_RA
J4: 112A-TAAR-R03_ATTEND""; 112ATAARR03ATTEND
L1: 68uH; IND_4828-WE-TPC_WRE
PFMF.050.1: ESP32C6_VARISTORCN1812; ESP32C6_VARISTOR_CT/CN1812
Q1, Q2: 20V/4.2A/52mΩ/1.4W; ESP32_WROVER_SPARKFUN-DISCRETESEMI_SOT23-3; PARTNAME DMG2305UX-7
Q3: SI1308EDL-T1-GE3; SOT65P210X110-3N
R1, R1-PINH, R1-PINH1, R2-PINH, R2-PINH1, R3, R4, R5, R6, R7, R8, R9, R10: 10K; ESP32_WROVER_EAGLE-LTSPICE_R0402
R1_BAT: 200; ESP32_WROVER_EAGLE-LTSPICE_R0402
R1_PWRUSB: 100K; ESP32_WROVER_EAGLE-LTSPICE_R0402
R2: 2.2; ESP32_WROVER_EAGLE-LTSPICE_R0402
R2-USB, R2-USB1: 5k1; ESP32_WROVER_EAGLE-LTSPICE_R0402
R2_BAT: 2K; ESP32_WROVER_EAGLE-LTSPICE_R0402
RESET_BUTTON: BUTTON_CUSYOMV1; MYBUTTON
R_BOOT: 10K; ESP32_WROVER_EAGLE-LTSPICE_R0402
R_CAPACITOR: 15; ESP32_WROVER_EAGLE-LTSPICE_R0402
R_CHANGE: 10K; ESP32_WROVER_EAGLE-LTSPICE_R0402
R_CL1: 10K; ESP32_WROVER_EAGLE-LTSPICE_R0402
R_RESET: 10K; ESP32_WROVER_EAGLE-LTSPICE_R0402
SENSOR2: ESP32_WROVER_BME680_BME680""; ESP32_WROVER_BME680_PSON80P300X300X100-8N
SJ1: SJ
TP_3V3: TPTP20R; TP20R
TP_EPD_3V3, TP_EPD_3V3_C: TPTP20R; TP20R
TP_EPD_BUSY: TPTP20R; TP20R
TP_EPD_CS: TPTP20R; TP20R
TP_EPD_DC: TPTP20R; TP20R
TP_EPD_RST: TPTP20R; TP20R
TP_GND: TPTP20R; TP20R
TP_GND_1: TPTP20R; TP20R
TP_INT_RTC: TPTP20R; TP20R
TP_MISO: TPTP20R; TP20R
TP_MOSI: TPTP20R; TP20R
TP_RX: TPTP20R; TP20R
TP_SCK: TPTP20R; TP20R
TP_TX: TPTP20R; TP20R
TP_VBAT: TPTP20R; TP20R
TP_VBUS: TPTP20R; TP20R
U1: W25Q512JVEIQ; SON127P600X800X80-9N
U2: ESP32-C6-WROOM-1-N8""; XCVR_ESP32-C6-WROOM-1-N8
U3: DS3231SN#""; SOIC127P1032X265-16N
U4: MAX17048G+T10; SON50P200X200X80-9N
U5: MCP73831; ESP32_WROVER_SPARKFUN-IC-POWER_SOT23-5

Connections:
3V3: C1_BAT2.1, C3.+, C9.1, D7.2 (ANODE), IC1.2 (VDD), IC4.5 (VOUT), J3.2, J4.P4 (VDD), Q2.3 (D), R1.2, R1-PINH1.2, R2-PINH1.2, R5.2, R6.2, R7.2, R8.2, R9.2, R10.2, R_BOOT.2, R_CHANGE.2, R_CL1.1, R_RESET.2, TP_3V3.TP, U1.3 (!WP!(IO2)), U1.7 (!HOLD!/!RESET!(IO3)), U1.8 (VCC), U2.2 (3V3), U3.2 (VCC)
32KHZ: R2-PINH1.1, U2.9 (IO1), U3.1 (32KHZ)
DN: D1.4 (I/O2_2), J2.A7, J2.B7
DP: D1.6 (I/O1_2), J2.A6, J2.B6
EPD_3V3: C7.1, EPD_C5.1, J1.15, J1.16, L1.2, Q2.2 (S), TP_EPD_3V3.TP
EPD_3V3_C: Q2.1 (G), R_CL1.2, TP_EPD_3V3_C.TP, U2.18 (IO20)
EPD_BUSY: J1.9, TP_EPD_BUSY.TP, U2.26 (IO3)
EPD_CS: D6.2, J1.12, R9.1, TP_EPD_CS.TP, U2.11 (IO10)
EPD_DC: J1.11, TP_EPD_DC.TP, U2.5 (IO5)
EPD_RST: J1.10, TP_EPD_RST.TP, U2.21 (IO23)
FLASH_CS: D9.2, R5.1, U1.1 (!CS), U2.12 (IO11)
GDR: J1.2, Q3.1 (G), R4.1
GND: BOOT_BUTTON.1, BOOT_BUTTON.2, C1.2, C1_BAT.2, C1_BAT1.2, C1_BAT2.2, C2.2, C2_BAT\.2, C3.-, C4_USB.2, C5.2, C5_USB.2, C6.2, C7.2, C8.2, C9.2, C10.2, C10_SUPERCAP.1, CHANGE_BUTTON.1, CHANGE_BUTTON.2, C_DELAY.2, D1.2 (GND), D3.1 (K), D6.1, D8.1, D9.1, D10.1, D11.1, D12.1, EPD_C1.2, EPD_C2.2, EPD_C5.2, EPD_C6.2, EPD_C7.2, EPD_C8.2, EPD_C9.2, EPD_C10.2, EPD_C11.2, EPD_C12.2, IC1.3 (GND), IC4.2 (VSS), J1.8, J1.17, J1.MP1, J1.MP2, J2.A1, J2.A12, J2.B1, J2.B12, J2.MP1, J2.MP2, J2.MP3, J2.MP4, J3.1, J4.G1 (GND_1), J4.G2 (GND_2), J4.G3 (GND_3), J4.G4 (GND_4), J4.P6 (VSS), R1_PWRUSB.1, R2.1, R2-USB.2, R2-USB1.1, R2_BAT.1, R4.2, RESET_BUTTON.1, RESET_BUTTON.2, SENSOR2.1 (GND), SENSOR2.5 (SDO), SENSOR2.7 (GND), SJ1.1, TP_GND.TP, TP_GND_1.TP, U1.4 (GND), U1.9 (EXP), U2.1 (GND), U2.28 (GND), U2.29_1 (GND), U2.29_2 (GND), U2.29_3 (GND), U2.29_4 (GND), U2.29_5 (GND), U2.29_6 (GND), U2.29_7 (GND), U2.29_8 (GND), U2.29_9 (GND), U3.13 (GND), U4.1 (CTG), U4.4 (GND), U4.6 (QSTRT), U4.9 (EP), U5.2 (VSS)
I2C_PW: C1.1, C2.1, R1-PINH.2, R2-PINH.2, SENSOR2.2 (CSB), SENSOR2.6 (VDDIO), SENSOR2.8 (VDD), U2.17 (IO19)
INT_RTC: R1-PINH1.1, TP_INT_RTC.TP, U2.8 (IO0), U3.3 (SQW/!INT)
IO/BOOT: BOOT_BUTTON.3, BOOT_BUTTON.4, C6.1, R_BOOT.1, U2.15 (IO9)
IO/CHANGE: C10.1, CHANGE_BUTTON.3, CHANGE_BUTTON.4, R_CHANGE.1, U2.23 (IO15)
MISO: D12.2, J4.P7 (DAT0), R8.1, TP_MISO.TP, U1.2 (DO(IO1)), U2.27 (IO2)
MOSI: D11.2, J1.14, J4.P3 (CMD), R7.1, TP_MOSI.TP, U1.5 (DI(IO0)), U2.7 (IO7)
unnamed: J2.B5, R2-USB.1
unnamed: C1_BAT1.1, D2.1 (CATHODE), IC4.1 (VIN), IC4.3 (CE), Q1.2 (S)
unnamed: R1.1, U2.10 (IO8)
unnamed: D7.1 (CATHODE), R_CAPACITOR.2
unnamed: EPD_C1.1, J1.4
unnamed: J2.A5, R2-USB1.2
unnamed: EPD_C2.1, J1.5
unnamed: EPD_C6.1, J1.18
unnamed: EPD_C7.1, J1.19
unnamed: EPD_C8.1, J1.20
unnamed: C_DELAY.1, IC1.5 (CT)
unnamed: EPD_C10.1, J1.22
unnamed: C4.1, D3.2 (A), D4.1 (K)
unnamed: EPD_C12.1, J1.24
unnamed: R1_BAT.1, U5.1 (STAT)
unnamed: CHG_LED.C, R1_BAT.2
unnamed: R2_BAT.2, U5.5 (PROG)
PREVGH: D5.1 (K), EPD_C9.1, J1.21
PREVGL: D4.2 (A), EPD_C11.1, J1.23
RESE: J1.3, Q3.2 (S), R3.1
RESE': R2.2, R3.2, SJ1.2
RESET: C5.1, IC1.1 (VOUT), RESET_BUTTON.3, RESET_BUTTON.4, R_RESET.1, U2.3 (EN)
RTC_RST: U2.16 (IO18), U3.4 (!RST)
RX: TP_RX.TP, U2.24 (RXD0/GPIO17)
SCK: D10.2, J1.13, J4.P5 (CLK), R6.1, TP_SCK.TP, U1.6 (CLK), U2.6 (IO6)
SCL: J3.4, R2-PINH.1, SENSOR2.4 (SCK), U2.20 (IO22), U3.16 (SCL), U4.7 (SCL)
SDA: J3.3, R1-PINH.1, SENSOR2.3 (SDI), U2.19 (IO21), U3.15 (SDA), U4.8 (SDA)
SRC: C4.2, D5.2 (A), L1.1, Q3.3 (D)
SS_SD: D8.2, J4.P2 (CD/DAT3), R10.1, U2.4 (IO4)
TX: TP_TX.TP, U2.25 (TXD0/GPIO16)
USB_D+: D1.1 (I/O1_1), U2.14 (IO13)
USB_D-: D1.3 (I/O2_1), U2.13 (IO12)
VBAT: C2_BAT\.1, Q1.3 (D), TP_VBAT.TP, U4.2 (CELL), U4.3 (VDD), U5.3 (VBAT)
VBUS: C1_BAT.1, C4_USB.1, C5_USB.1, CHG_LED.A, D1.5 (VBUS), D2.2 (ANODE), PFMF.050.1.2, Q1.1 (G), R1_PWRUSB.2, TP_VBUS.TP, U5.4 (VIN)
VRTC: C8.1, C10_SUPERCAP.2, R_CAPACITOR.1, U3.14 (VBAT)
VUSB: J2.A4, J2.A9, J2.B4, J2.B9, PFMF.050.1.1

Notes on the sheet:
USB C connector & ESD protection
LDO Voltage Regulator
SD Card
ESP32 C6
Battery Charge Level
External NOR Flash 64MB
SPI ESD Protection Lines
Qwiic / Stemma QT
Test Pads
RTC Module DS3231SN
E-Paper Display Header
EPD Power
Environmental Sensor BME688
Voltage Supervisor + Reset & Boot / IO Button
Display Type Selector
E-Paper Drive Circuit
Li-Po Battery Charging Controller

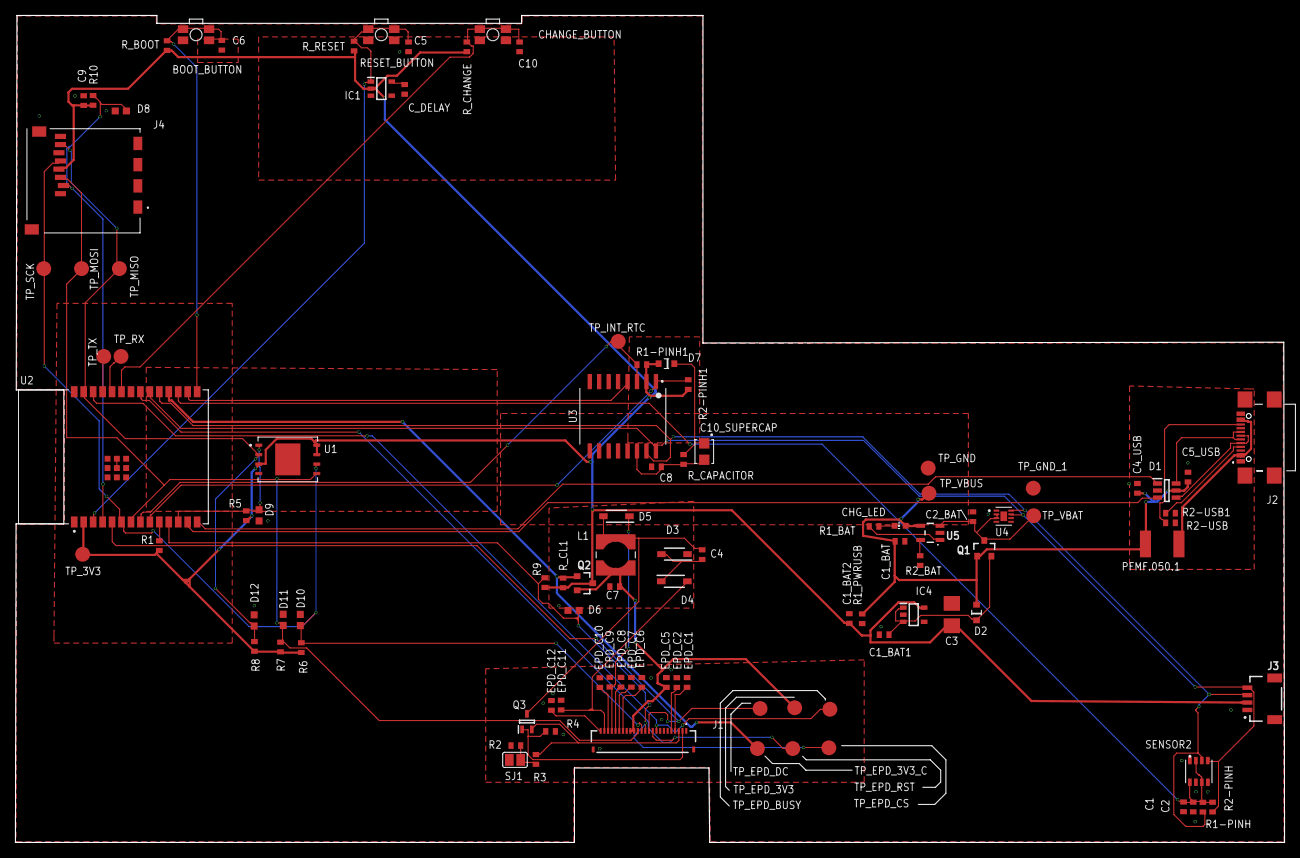
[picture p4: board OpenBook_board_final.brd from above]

Board: 2 copper layers, 170.5 x 111.1 mm, 103 parts (0 on the bottom side), 55 nets.

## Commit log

2025-04-04 Added most of the files - Mechanical was too big
    Had to make Mechanical a zip to fit it. README is left
    [OpenBook_Board.brd, OpenBook_Schematic.sch, PnP_OpenBook v60_front.csv]
2025-04-14 Added updated board file
    [OpenBook_board_final.brd]
